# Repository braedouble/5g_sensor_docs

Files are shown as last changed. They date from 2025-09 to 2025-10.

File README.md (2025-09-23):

# Hardware
- My sensor (Diagram)
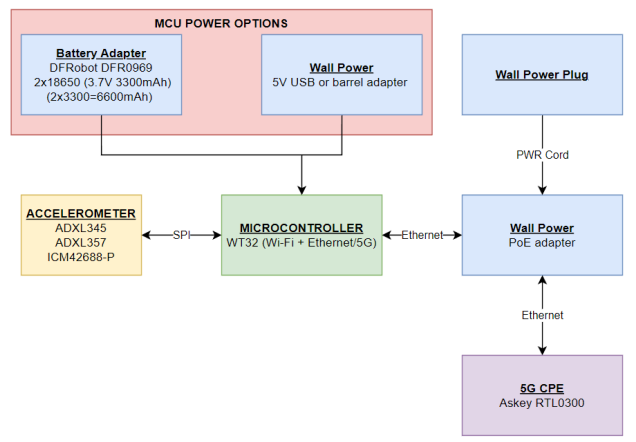
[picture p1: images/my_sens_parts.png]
My sensor parts
	- 
- My sensor (On shaker)
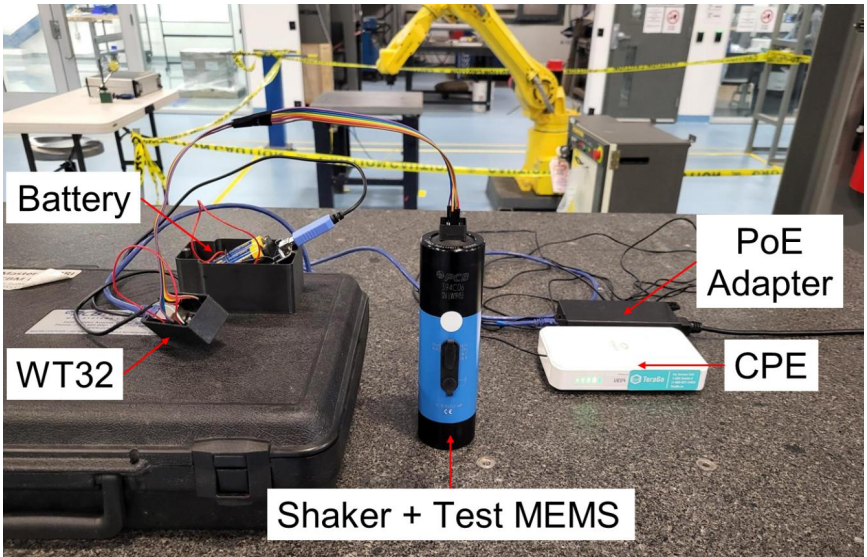
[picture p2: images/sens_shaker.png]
Sensor on shaker
	- 
## 5G Connection
- Sensor connects to 5G via ethernet CPE access point
- Connects to a device connected directly to the 5G core server
	- This port is connected to an ethernet port in the lab, the local breakout port (LBO)
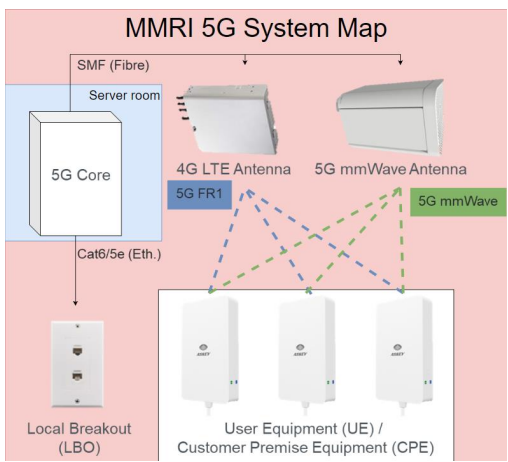
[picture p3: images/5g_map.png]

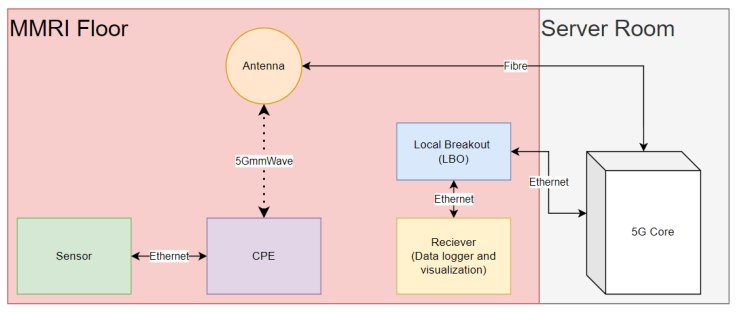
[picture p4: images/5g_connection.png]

## MCU
- WT32 - all important info below
	- https://github.com/egnor/wt32-eth01 (Guide)
		- most helpful for setup, tricks for WT32
		- HOW TO PROGRAM -> program mode vs run mode (IO0)
	- https://en.wireless-tag.com/product-item-2.html (INFO)

## Accelerometer
All read via SPI (analog sensor add ADC)
- ICM42688-P
	- Custom PCB (datasheet pg. 21 typical operating circuit)
		- Included in files
		- Easy for me to order more, just contact me
	- https://invensense.tdk.com/products/motion-tracking/6-axis/icm-42688-p/ (INFO)
	- https://invensense.tdk.com/wp-content/uploads/2020/04/ds-000347_icm-42688-p-datasheet.pdf (DATASHEET)
# Software
## Libraries
All info based on register functions from accelerometer datasheets
- ICM42688-P
	- mainly based on https://github.com/finani/ICM42688
	- some changes to try to make SPI reads faster and match some functions to my other accelerometer libraries
	- did some work to get FIFO working to try for 32 kHz output
	- tested and working with 5G and ethernet at 16kHz ODR with interrupt method
## Platformio/ESP32
- Used for code uploading 
	- https://randomnerdtutorials.com/vs-code-platformio-ide-esp32-esp8266-arduino/
		- GOOD GUIDE - platformio for esp32 install and setup
	- https://platformio.org/install
	- https://docs.platformio.org/en/latest/boards/espressif32/wt32-eth01.html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
		- WT32 board setup (select for board in platformio)
## Receiver
- Require python and matplotlib library (rest of libraries should be built in)
# Setup
- Follow platformio setup
- Setup WT32 for programming per the guide
- Code should be okay to upload to sensor
	- sensor
		- set IP address and port number of receiver 
	- receiver
		- match port number to sensor
- Change to run mode and connect to a python reader
## FOR SENSOR
- Needs valid network info (reader IP address and port)
- Sensor settings for Hz and range are set via code still I think for ICM, controls need to be finished
- 16kHz max ODR for SPI without FIFO right now
## FOR RECEIVER
- Needs port set for same as reader 
- Needs sensor on and running first
# Lathe Tool Holder Previous Works
- Bleicher 2018, 2020, 2023 (Milling)
  	- Schorghofer 2019
	- Ramsauer 2021 (not much sensor info added here)
## Main Changes
- Mounting (tool holder)
	- machine considerations (chips, coolant, heat)
	- cpe placement / battery life
- Read selected sensors
- Rec./Controller updates + database implementation
- Sensor connection / reconnection handling

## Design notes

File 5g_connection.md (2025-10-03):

# MMRI 5G Connection
- 1 Gbps connection from 5G core to ethernet at front post (A106-65)
- IP address of device connected to this port (LBO) gets a static IP and will be routed to the UE subnet (192.168.241.XXX)
    - LBO STATIC IP ADDRESS INFO
    - IP: 192.168.254.100-110
    - Subnet Mask: 255.255.255.0 (24 length)
    - Gateway: 192.168.254.1
- UE device should use dynamic IP address
    - Will recieve a 192.168.241.XXX IP address, is routed to 192.168.254.XXX and will allow you to ping
- To test connection
    - Ping gateway (192.168.254.1)
    - Ping Core <---> UE device both ways

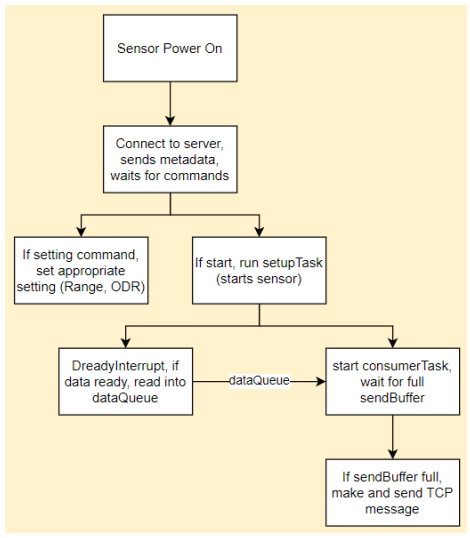
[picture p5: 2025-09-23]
images/sens_code_basic.png

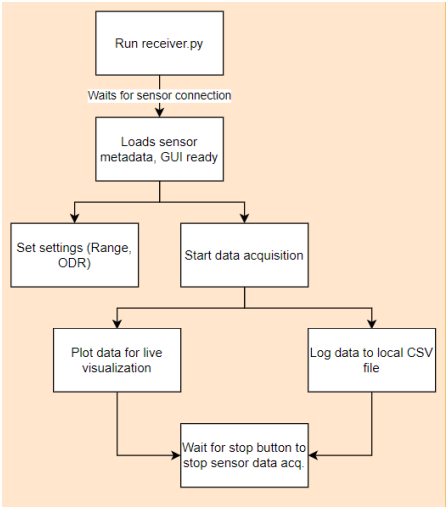
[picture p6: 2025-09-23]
images/sens_rec.png

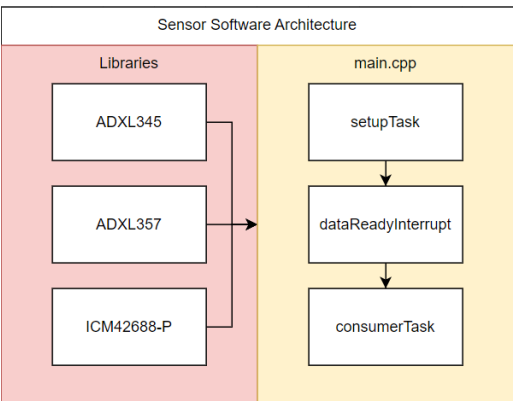
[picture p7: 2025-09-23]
images/sens_libs.png

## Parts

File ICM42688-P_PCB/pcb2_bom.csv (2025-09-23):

Reference | Value | Footprint | JLCPCB Part # | Package | Qty
C1 | .1uF | Capacitor_SMD:C_0402_1005Metric | C1525 | 0402 | 1
C2 | 2.2uF | Capacitor_SMD:C_0402_1005Metric | C12530 | 0402 | 1
C3 | 10nF | Capacitor_SMD:C_0402_1005Metric | C15195 | 0402 | 1
H1-H4 | MountingHole | MountingHole:MountingHole_3mm |  |  | 4
J1, J2 | Conn_01x04_Pin | Connector_PinHeader_2.54mm:PinHeader_1x04_P2.54mm_Vertical |  |  | 2
U1 | ICM-42688-P | ICM-42688-P:PQFN50P300X250X97-14N | C1850418 | LGA-14 TDK InvenSense | 1

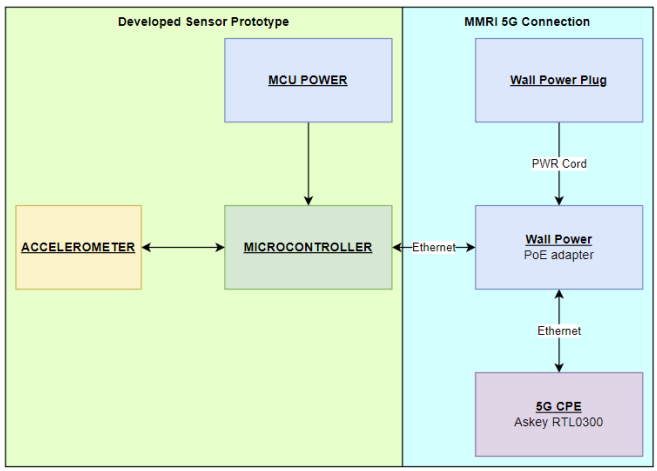
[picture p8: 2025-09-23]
images/sens_parts.png

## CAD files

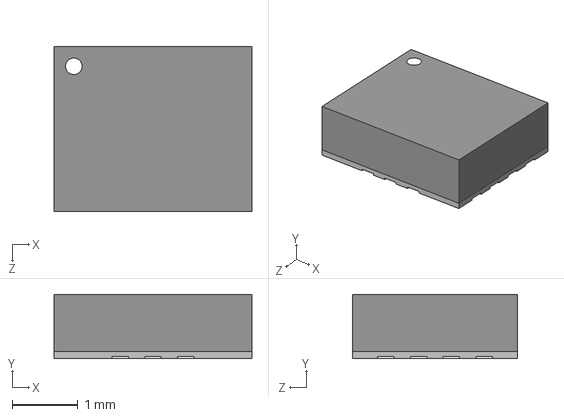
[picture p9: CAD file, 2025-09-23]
ICM42688-P_PCB/pcb2/ICM-42688-P/ICM-42688-P.step
3.00 x 0.97 x 2.50 mm

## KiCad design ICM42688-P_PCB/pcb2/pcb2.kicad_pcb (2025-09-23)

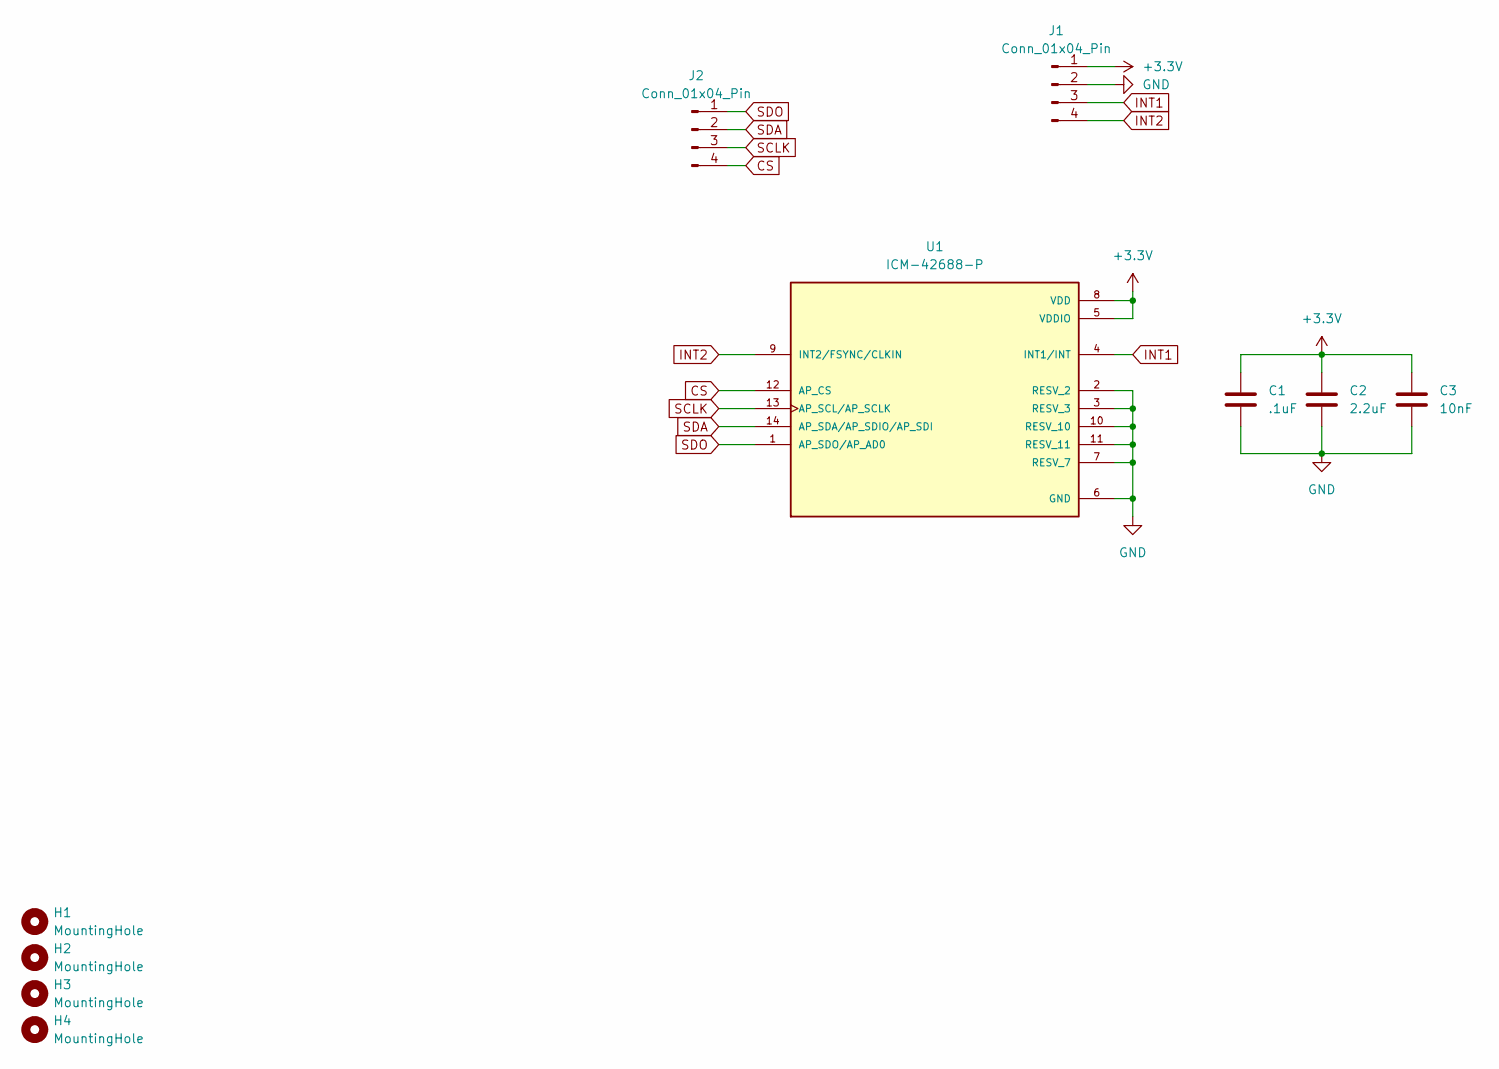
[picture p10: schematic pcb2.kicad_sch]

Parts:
C1: .1uF; C_0402_1005Metric; JLCPCB Part # C1525
C2: 2.2uF; C_0402_1005Metric; JLCPCB Part # C12530
C3: 10nF; C_0402_1005Metric; JLCPCB Part # C15195
H1, H2, H3, H4: MountingHole; MountingHole_3mm
J1, J2: Conn_01x04_Pin; PinHeader_1x04_P2.54mm_Vertical
U1: ICM-42688-P; PQFN50P300X250X97-14N; PARTREV 1.2; JLCPCB Part # C1850418

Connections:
+3.3V: C1.1, C2.1, C3.1, J1.1, U1.5 (VDDIO), U1.8 (VDD)
CS: J2.4, U1.12 (AP_CS)
GND: C1.2, C2.2, C3.2, J1.2, U1.2 (RESV_2), U1.3 (RESV_3), U1.6 (GND), U1.7 (RESV_7), U1.10 (RESV_10), U1.11 (RESV_11)
INT1: J1.3, U1.4 (INT1/INT)
INT2: J1.4, U1.9 (INT2/FSYNC/CLKIN)
SCLK: J2.3, U1.13 (AP_SCL/AP_SCLK)
SDA: J2.2, U1.14 (AP_SDA/AP_SDIO/AP_SDI)
SDO: J2.1, U1.1 (AP_SDO/AP_AD0)

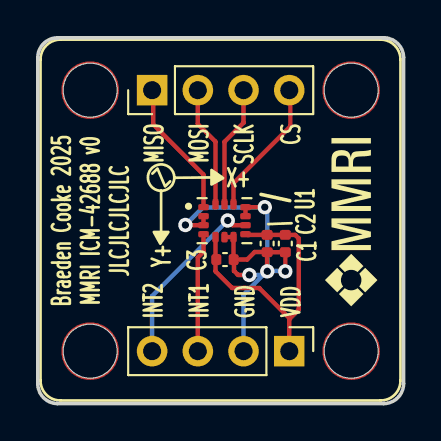
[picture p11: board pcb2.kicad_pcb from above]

Board: 2 copper layers, 20.3 x 20.3 mm, 10 parts (0 on the bottom side), 8 nets.

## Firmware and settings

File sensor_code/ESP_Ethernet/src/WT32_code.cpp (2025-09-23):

// https://docs.espressif.com/projects/esp-idf/en/latest/esp32/api-reference/system/freertos_idf.html#tasks

// include the necessary headers for Arduino and FreeRTOS.
#include <Arduino.h>

#include "freertos/FreeRTOS.h"
#include "freertos/task.h"
#include "freertos/queue.h"
#include "freertos/semphr.h"

// for accel reading
#include "ICM42688.h"        
#include <SPI.h>

#include <ETH.h>
#include <esp_task_wdt.h>

#define BUFFER_SIZE 1460 
char sendBuffer[BUFFER_SIZE];
int bufferIndex = 0;
int lastSendTime = 0;

// for receiver setting info
#define sensType "ICM42688" 
#define defaultRate 1000 // default ODR 
float LPF_rate = defaultRate;
#define defaultRange 16 // default range = +-16g
int sensRange = defaultRange; // sens range setting ICM42688 = 2, 4, 8, 16g

// WT32 int pin
int int_pin = 32;

int status = WL_IDLE_STATUS;
//IPAddress server(192,168,0,11);
//IPAddress server(192,168,254,102);
//IPAddress server(192,168,50,145);
IPAddress server(192, 168, 50, 197);
//IPAddress server(192,168,254,101);
WiFiClient client;

// FOR ACCELEROMETER
ICM42688 IMU(SPI, 5, 24000000); // Initialize IMU - ICM42688(SPI_BUS, CS_PIN, SPI_CLK);

// initialize variables for command handling
enum RunMode { CONTINUOUS, TIMED, SETUP };
RunMode currentMode = SETUP;
String commandBuffer = ""; // Buffer for bits from incoming commands
String inputCommand = ""; // To store incoming commands
unsigned long runDuration = 0; // In microseconds
unsigned long modeStartTime = 0;

void startSendingData();
void stopSendingData();
void parseCommand(String);

TaskHandle_t setupHandle = NULL;
void setupTask(void *pvParameters) {
  
  //loop - read incoming
  while (1){
    if (client.connected() && client.available() > 0) {
        client.setNoDelay(true); // Disable Nagle's algorithm
        char incomingChar = client.read(); // Read a single character
        if (incomingChar == '\n') { // End of command
            parseCommand(commandBuffer); // Pass the complete command to the parser
            commandBuffer = ""; // Clear the buffer for the next command
        } else {
            commandBuffer += incomingChar; // Append the character to the buffer
        }
    }
    else{
         vTaskDelay(pdMS_TO_TICKS(10)); // 10 ms delay
    }
  }
}

void parseCommand(String command) {
  // debug print
  Serial.print("Received command: ");
  Serial.println(command);

  command.trim(); // Clean up the command string
  

  if (command.equalsIgnoreCase("START_CONTINUOUS")) {
      currentMode = CONTINUOUS;
      client.println("Started continuous mode.");
      startSendingData();
  } else if (command.startsWith("START_TIMED")) {
      int duration = command.substring(11).toInt();
      if (duration > 0) {
          currentMode = TIMED;
          runDuration = duration * 1000; // Convert ms to µs
          modeStartTime = micros();
          client.printf("Started timed mode for %d ms.\n", duration);
          startSendingData();
      } else {
          client.println("Error: Invalid duration.");
      }
  } else if (command.equalsIgnoreCase("STOP")) {
      stopSendingData();
      client.println("Stopped.");
      currentMode = SETUP;
  } else if (command.startsWith("SET_RANGE")) {
      int range = command.substring(9).toInt();
      if (range == 2 || range == 4 || range == 8 || range == 16){ // for ICM42688
        //adxl.setRangeSetting(range);
        switch(range) {
          case 2: sensRange=2; break; // for ICM42688
          case 4:  sensRange=4; break;
          case 8:  sensRange=8; break;
          case 16: sensRange=16; break;
          }
        client.printf("Range set to %d.\n", range);
        Serial.printf("Range set to %d.\n", range);
      }
      else{
        client.printf("%d is an invalid range for %s.\n", range, sensType);
        Serial.printf("%d is an invalid range for %s.\n", range, sensType);
      }
  } else if (command.startsWith("SET_FREQUENCY")) {
      // *needs validation*
      float frequency = command.substring(13).toFloat();
      
      if (frequency > 0) {
          //adxl.setRate(frequency);
          //LPF_rate = frequency/4;
          client.printf("Frequency set to %.2f Hz.\n", frequency/4); // 4 is 2 for ADXL345 BW to ODR
      } else {
          client.printf("Error: Invalid frequency %f.\n", frequency/4); // 4 is 2 for ADXL345 BW to ODR
      }
  } else {
      client.println("Error: Unknown command.");
  }
}

// FOR ACCELEROMETER
// OPTIMIZED DATA STRUCTURE - Pack to reduce memory bandwidth [ __attribute__((packed)) ]
struct accelData {
  uint16_t delta_t; //
  int16_t x, y, z;  //
};


// FOR QUEUE
TaskHandle_t consumerHandle = NULL;
bool sendingData = false;
QueueHandle_t dataQueue;

// IRAM ideal for interrupts (placing a function into IRAM may reduce delays caused by a cache miss and significantly improve that function's performance)
// IRAM vs ARDUINO_ISR_ATTR?? https://docs.espressif.com/projects/arduino-esp32/en/latest/api/gpio.html?highlight=pullup#interrupts

static volatile bool dataReady = false;
static volatile accelData isrData;
static unsigned long lastTime = 0;
unsigned long startTime;


void IRAM_ATTR onDRDYInterrupt() {
    //static accelData accelData;
    //accelData.delta_t = 0; // Delta time calculated in consumer task
    
    unsigned long currentTime = micros() - startTime;
    uint16_t deltaT = (lastTime == 0) ? 0 : (currentTime - lastTime);
    lastTime = currentTime;
  
    // For ICM42688

    IMU.getRawAGT();
    isrData.delta_t = deltaT;    // read sensor data into buffers
    isrData.x = (int16_t)IMU.rawAccX();
    isrData.y = (int16_t)IMU.rawAccY();
    isrData.z = (int16_t)IMU.rawAccZ(); // get the data from the buffers

    // Quick queue send - use higher priority version
    BaseType_t xHigherPriorityTaskWoken = pdFALSE;
    xQueueSendFromISR(dataQueue, (void *)&isrData, &xHigherPriorityTaskWoken);

    // Force context switch if needed
    if (xHigherPriorityTaskWoken) {
      portYIELD_FROM_ISR();
    }
}

void startSendingData() {
  Serial.println("Starting...");
  sendingData = true;
  startTime = micros();

  lastTime = 0;

  // Clear queue before starting
  accelData dummyData;
  while (xQueueReceive(dataQueue, &dummyData, 0) == pdTRUE) {
    // Empty the queue
  }

  vTaskResume(consumerHandle);
  // For ICM42688
  //IMU.setFilters(0,0);
  Serial.println(IMU.begin());
  IMU.setAccelODR(ICM42688::odr16k);
  switch (sensRange) {
  case 2:
    IMU.setAccelFS(ICM42688::gpm2);
    break; // for ICM42688
  case 4:
    IMU.setAccelFS(ICM42688::gpm4);
    break;
  case 8:
    IMU.setAccelFS(ICM42688::gpm8);
    break;
  case 16:
    IMU.setAccelFS(ICM42688::gpm16);
    break;
  }
  IMU.setFilters(0, 0);
  IMU.enableDataReadyInterrupt();

  // Re-enable the interrupt after sensor is ready
  //attachInterrupt(int_pin, onDRDYInterrupt, RISING || ONHIGH);
  attachInterrupt(int_pin, onDRDYInterrupt, CHANGE);

  vTaskSuspend(setupHandle);
}

void stopSendingData() {

  // First disable the interrupt to prevent new data
  detachInterrupt(int_pin);

  // For ICM42688
  IMU.disableDataReadyInterrupt();

  Serial.println("Sensor stopped.");
  sendingData = false;

  // Clear send buffer
  bufferIndex = 0;
  memset(sendBuffer, 0, BUFFER_SIZE);
  
  // Give time for the queue to clear
  vTaskDelay(pdMS_TO_TICKS(100));
  
  // Clear any remaining items in queue
  accelData dummyData;
  while (xQueueReceive(dataQueue, &dummyData, 0) == pdTRUE) {
    // Empty the queue
  
  client.flush(); //flush remaining data from client 
  }
  
  vTaskResume(setupHandle);
  vTaskSuspend(consumerHandle);
}


// consumer task
void consumerTask(void *pvParameters) {
  accelData receivedData;
  int msgCount = 0;
  const TickType_t xTicksToWait = pdMS_TO_TICKS(1); 

  while (1) {
    if (!sendingData) {
      vTaskDelay(pdMS_TO_TICKS(10));
      continue;
    }

    // Process multiple queue items per iteration
    int itemsProcessed = 0;
    while (itemsProcessed < 10 &&
           xQueueReceive(dataQueue, &receivedData,
                         (itemsProcessed == 0) ? xTicksToWait : 0) == pdTRUE) {
      // Check for buffer space
      if (bufferIndex + sizeof(accelData) > BUFFER_SIZE) {
        if (client.connected()) {
          size_t sent = client.write(sendBuffer, bufferIndex);
          if (sent != bufferIndex) {
            Serial.printf("Write failed: sent %d of %d\n", sent, bufferIndex);
          }
        }
        bufferIndex = 0;
        msgCount++;
        lastSendTime = micros();
      }

      // Copy data to buffer
      memcpy(sendBuffer + bufferIndex, &receivedData, sizeof(accelData));
      bufferIndex += sizeof(accelData);
      itemsProcessed++;

      // Send when buffer is nearly full
      if (bufferIndex >= BUFFER_SIZE - sizeof(accelData)) {
        if (client.connected()) {
          size_t sent = client.write(sendBuffer, bufferIndex);
          if (sent != bufferIndex) {
            Serial.printf("Write failed: sent %d of %d\n", sent, bufferIndex);
          }
        }
        bufferIndex = 0;
        msgCount++;
        lastSendTime = micros();
      }
    }

    if (bufferIndex > 0 &&
        (micros() - lastSendTime) > 5000) { // 
      if (client.connected()) {
        size_t sent = client.write(sendBuffer, bufferIndex);
        if (sent != bufferIndex) {
          Serial.printf("Write failed: sent %d of %d\n", sent, bufferIndex);
        }
      }
      bufferIndex = 0;
      msgCount++;
      lastSendTime = micros();
    }

    if (itemsProcessed == 0) {
      taskYIELD();
    }
  }
}

TimerHandle_t ethReconnectTimer;
void connectToEth() {
    if (ETH.begin()) {
        Serial.println("ETH begun");
        //startSendingData();
    } else {
        Serial.println("ETH Failed to begin. Restarting...");
        ESP.restart();
    }
}

void WiFiEvent(WiFiEvent_t event) {
    switch (event) {
        case ARDUINO_EVENT_ETH_START:
            Serial.println("ETH Started");
            //set eth hostname here
            ETH.setHostname("esp32-ethernet");
            break;
        case ARDUINO_EVENT_ETH_CONNECTED:
            Serial.println("ETH Connected");
            break;
        case ARDUINO_EVENT_ETH_GOT_IP:
            Serial.print("ETH MAC: ");
            Serial.print(ETH.macAddress());
            Serial.print(", IPv4: ");
            Serial.print(ETH.localIP());
            if (ETH.fullDuplex()) {
                Serial.print(", FULL_DUPLEX");
            }
            Serial.print(", ");
            Serial.print(ETH.linkSpeed());
            Serial.println("Mbps");
            if (client.connect(server, 81)) {
              Serial.println("connected");
              client.printf("SENSOR_INFO:%s,%d,%g\n", sensType, sensRange, LPF_rate*4);
              Serial.printf("SENSOR_INFO:%s,%d,%g\n", sensType, sensRange,
                        LPF_rate * 4);
            }
            break;
        case ARDUINO_EVENT_ETH_DISCONNECTED:
            Serial.println("ETH Disconnected");
            xTimerStart(ethReconnectTimer, 0);
            break;
        case ARDUINO_EVENT_ETH_STOP:
            Serial.println("ETH Stopped");
            xTimerStart(ethReconnectTimer, 0);
            break;
        default:
            break;
    }
}


void setup() {

  Serial.begin(921600);
  delay(1000);

  WiFi.onEvent(WiFiEvent);
  connectToEth();
  ethReconnectTimer = xTimerCreate("ethTimer", pdMS_TO_TICKS(2000), pdFALSE, (void*)0, reinterpret_cast<TimerCallbackFunction_t>(connectToEth));

  // Create queue
  dataQueue = xQueueCreate(8192, sizeof(accelData));  // (max # of items, single item size)

  // Configure task watchdog timer (optional)
  esp_task_wdt_init(5, true); // 5 second timeout, panic on timeout
  
  // Create consumerTask pinned to core 1
  xTaskCreatePinnedToCore(consumerTask, "consumerTask",
                          12288 , // 8192, //10000
                          NULL,
                          5, &consumerHandle, 1);

  vTaskSuspend(consumerHandle);
  
  xTaskCreatePinnedToCore(
    setupTask,
    "setupTask",
    5000,
    NULL,
    3,
    &setupHandle,
    0
  );
}

void loop() {
   // The loop function is empty because our tasks are running independently
}

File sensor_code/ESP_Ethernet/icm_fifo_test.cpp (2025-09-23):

#include "ICM42688.h"
#include <Arduino.h>
#include <esp_task_wdt.h>
// TODO: Need to test this with the ICM42688

// an ICM42688 object with the ICM42688 sensor on SPI bus 0 and chip select pin 5
ICM42688_FIFO IMU(SPI, 5);
int           status;

// variables to hold FIFO data, these need to be large enough to hold the data
int ax[300], ay[300], az[300];
uint8_t h[300];
size_t fifoSize;

volatile bool imuDataReady = false;

void IRAM_ATTR onDRDYInterrupt() { imuDataReady = true; }

void processIMUData() {
  IMU.readFifo();

  size_t fifoSize;
  uint8_t h[300];
  int ax[300], ay[300], az[300];

  IMU.getFifoHeader(&fifoSize, h);
  IMU.getFifoAccelX_raw(&fifoSize, ax);
  IMU.getFifoAccelY_raw(&fifoSize, ay);
  IMU.getFifoAccelZ_raw(&fifoSize, az);

  Serial.print("The FIFO buffer is ");
  Serial.print(IMU.getFifoSize());
  Serial.println(" samples long.");
  for (size_t i = 0; i < fifoSize; i++) {
    Serial.print(h[i]);
    Serial.print("\t");
    Serial.print(ax[i]);
    Serial.print("\t");
    Serial.print(ay[i]);
    Serial.print("\t");
    Serial.println(az[i]);
  }
}

void setup() {
  Serial.begin(921600);
  attachInterrupt(32, onDRDYInterrupt, RISING);

  esp_task_wdt_init(5, true); // WDT for long loops

  status = IMU.begin();
  IMU.setAccelODR(ICM42688::odr4k);
  IMU.setFifoSize(100);
  IMU.setFilters(0, 0);
  IMU.resetInterrupts();
  IMU.enableFifoThresholdInterrupt();

  if (status < 0) {
    Serial.println("IMU initialization unsuccessful");
    Serial.println("Check IMU wiring or try cycling power");
    Serial.print("Status: ");
    Serial.println(status);
  }

  IMU.enableFifo(true, false, false);
  IMU.streamToFifo();
}

void loop() {
  if (imuDataReady) {
    imuDataReady = false;
    processIMUData();
  }

  // Optionally reset the Task WDT if you're using it for long-loop protection
  esp_task_wdt_reset();
}
